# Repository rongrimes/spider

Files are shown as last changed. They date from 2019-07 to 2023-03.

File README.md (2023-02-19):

# Heavy Metal Hollywood Spider
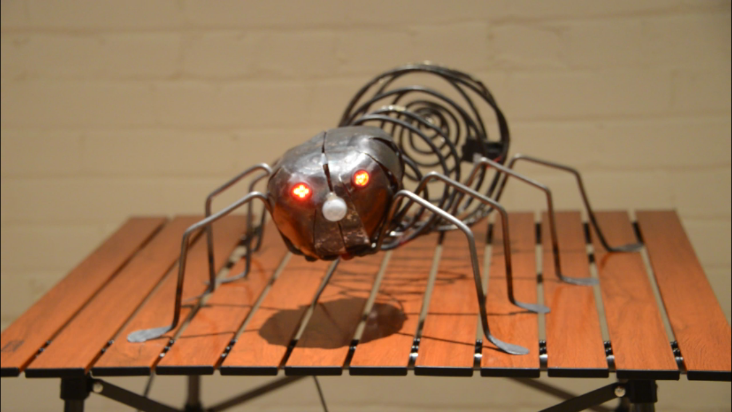
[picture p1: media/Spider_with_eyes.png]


**Heavy Metal Hollywood Spider** is an _*animatronics*_ project and is the fusion of two interests:
* Art Metal class
* Raspberry Pi and related hardware software.

As with the Chocolate Box News Reader ("paxnews"), the project grew organically. That is I had a rough idea how it would all look at the end but progress was consistent over a number of months. You could say that, he is an organic spider (best kind!).

Ultimately, HMHS became a successful Halloween prop.

## Components:
* [Raspberry Pi Zero W](https://www.buyapi.ca/product/raspberry-pi-zero-w/)
* Eyes: 2 clusters of 4 RGB LEDs
* [Adafruit I2S 3W Stereo Speaker Bonnet for Raspberry Pi](https://www.buyapi.ca/product/adafruit-i2s-3w-stereo-speaker-bonnet-for-raspberry-pi-mini-kit/)
  * includes 2 speakers 
* [PIR sensor](https://www.buyapi.ca/product/hc-sr501-pyroelectric-infrared-pir-motion-sensor-detector-module/)
* [LED string (white) or similar](https://www.staples.com/5ft-15-Soft-White-String-Lights-with-Timer-74445/product_2724775)
* [Simple RF M4 Receiver - 315MHz Momentary Type](https://www.buyapi.ca/product/simple-rf-m4-receiver-315mhz-momentary-type/)
* [Keyfob 4-Button RF Remote Control - 315MHz](https://www.buyapi.ca/product/keyfob-4-button-rf-remote-control-315mhz/)

## Spider Construction
The spider grew "organically" over two semesters of the **Art Metal** class held at <a href="https://www.danforthcti.com/">Danforth Collegiate</a> in the body shop workshop, under the auspices of the <a href="https://www.tdsb.on.ca/Adult-Learners/Learn4Life">TDSB Adult Learner Program</a> (Toronto District School Board). [Thanks to Phil and Toby for their guidance.]

## General Operations
The spider sensor resides in the nose and detects motion from pets/humanoids/zombie  up to 5 metres away (<a href="https://www.adafruit.com/product/189" target="_blank">possibly works on zombies, not guaranteed</a>).

On pet/humanoid/zombie detection:
* Spider is dozing: The cyan eyes and body lights twitch every few seconds. Until someone/thing comes by.
* Spider goes on alert: The cyan eyes and body lights start flashing rapidly.
* Spider gets angry: The red eyes then transition up to full brightness.
* Spider emits warning noises: A short sound clip plays twice (or other count) or until the pet/humanoid/zombie goes out of range.
* All clear, Spider goes back to sleep: The red eyes then transition down.
* Spider goes back to dozing.

### Spider video
Spider video.

(Click and view the raw file in a separate window.).

### Spider Control Subsystem
A 4-Button 315Mhz Keyfob RF Remote Control controls parameters of the spider: Sound On/Off, Sound Volume, Eye Intensity.

The keyfob controls a Simple RF M4 Receiver> with results fed through to four GPIO pins via separate simple voltage splitters to translate 5V to 3.3V (2.8V actually).

The program *key_parms.py* watches the remote control and updates a shared json file used by _spider.py_.

### Schematic
See schematic.  
(Remote control content is not shown.)

## Operations
Start spider with _crontab_:
```
@reboot rm -f /home/pi/python/spider/ospid.txt # JOB_ID_1; Remove pid file to prevent mulitiple incursions of spider.
@reboot sleep 1 && ~pi/run_spider.sh           # JOB_ID_2; start spider.
@reboot sleep 2 && stdbuf -oL ~pi/python/spider/key_parms.py >> /tmp/spider.txt  # JOB_ID_3; start key controller.
```

## Fob Commands
The key Fob/RF receiver controls parameters for operation: A Voice prompt guides the operator for the steps.
 ready for power off.  
1: Press D to get attention.  
2. Press D for the menu.  
   A > Sound On/Off  
   B > Sound Volume  
   C > Maximum eye intensity  
   D > Play the menu (and a seong press will Return to the outer shell ("1")).  
3. Three consecutive presses of D cause spider to shutdown and be ready for power off.  

## Voice Prompt
For the prommt voice clips, I used the text-to-voice service from [IBM Watson](https://text-to-speech-demo.ng.bluemix.net/). Most of the voices are slowed a little from their original speeds to add gravitas. A json file holds the key of voice clips to files, but also holds the markeed up text sent to Watson  in case the text needs editing.

## FAQ
Q: Why _Hollywood_?  
A: Well, we... the spider and me... live on Hollywood Cres.

***
Ron Grimes  
Toronto  
Started:     January 2019  
Last Update: November 2020

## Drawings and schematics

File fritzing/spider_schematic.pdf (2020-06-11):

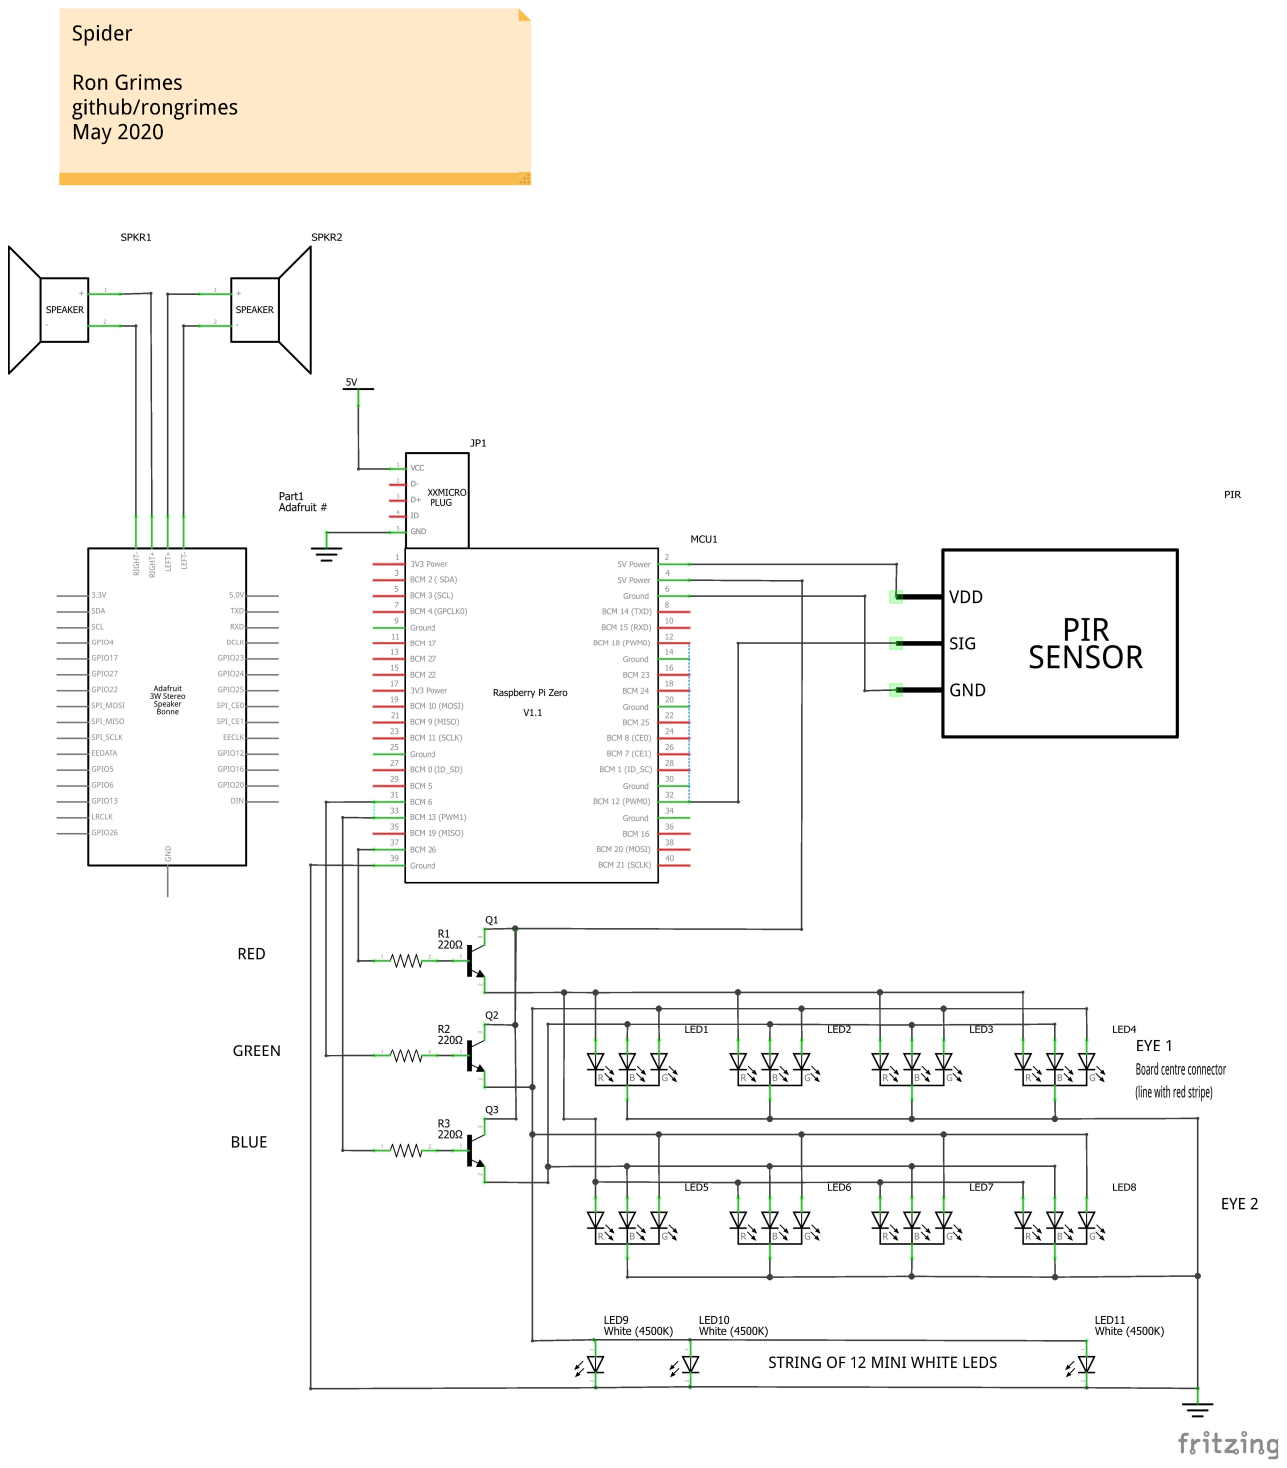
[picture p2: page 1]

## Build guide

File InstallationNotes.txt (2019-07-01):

Installation Notes for the Spider/Pi Zero
=========================================
(Notes: You will need to add reboots at opportune places).

1. Load Raspbian Stretch (not Lite); Img file 3.4GB

2. Load in to Pi Zero.

3. Standard initial settings, plus:
   In Raspberry Pi Config:
   a. Set platform name: raspberrypiZ1   
   b. set password.
   c. Enable ssh
   In Add/Remove Software:
   a. GNOME Onscreen Keyboard
   
4. Install:
   a. sudo apt install vim
   
5. Increase Swapsize:
    a. Stop the swap. sudo dphys-swapfile swapoff.
    b. Modify the size of the swap. As root , edit the file /etc/dphys-swapfile and modify the variable CONF_SWAPSIZE : CONF_SWAPSIZE=1024. ...
    c. Start the swap. sudo dphys-swapfile swapon.
	(ref: https://raspberrypi.stackexchange.com/questions/41150/virtual-keyboard-activation)

6. Install on-screen virtual keyboard.
    sudo apt-get install matchbox-keyboard
	(https://raspberrypi.stackexchange.com/questions/41150/virtual-keyboard-activation)
	
7. Create ~pi/python/spider

7. Load spider files from backup.

8. Load Speaker bonnet driver:
   curl -sS https://raw.githubusercontent.com/adafruit/Raspberry-Pi-Installer-Scripts/master/i2samp.sh | bash
   (ref: https://learn.adafruit.com/adafruit-speaker-bonnet-for-raspberry-pi/raspberry-pi-usage)

9. sudo apt install gnome-schedule
   This installs a GUI crontab entry system.
   Maybe unnecessary, but manual crontab was not producing results.

10. Alternative: "crontab -e" with:
    @reboot rm /home/pi/python/spider/ospid.txt # JOB_ID_2
    @reboot sleep 2 && ~pi/run_spider.sh # JOB_ID_1

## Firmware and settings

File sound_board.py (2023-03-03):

#!/usr/bin/python3
import asyncio
import json
import os
from random import randint

#----------------------------------------------------------------------------------------
class Sound_board:
    sound_dir       = "/home/pi/python/spider/clips/"
    sound_parmfile  = sound_dir + "soundparms.json"
    voice_volume    = 40000      # range: 0 - max  (1000000?)
    max_volume      = 40000    # range: 0 - max
    max_volume_limit = 60000 # can scale up the volume but limit it to this.

    def __init__(self):
        try:
            with open(self.sound_parmfile, "r") as f:
                self.sound_clips = json.load(f)
        except FileNotFoundError:
            print(self.sound_parmfile + ": not found. Reloading.")
            self._load_clips()
#       print(self.sound_clips)
        self.last_clip = None if len(self.sound_clips) == 0 else randint(0, len(self.sound_clips)-1)
#       self.clips_init = True     # lets us spin up through the clips if we use an async iterator

#---------------------------------------------------------------------------------
    def print_clips(self, sound_clips):
        for i, f in enumerate(sound_clips):
            print(f"{i}\t{f}")
        print()
        
    def _load_clips(self):
        self.sound_clips = []
        if not os.path.isdir(self.sound_dir):
            print(self.sound_dir + ": Sound dir does not exist.")
            return            # dir doesn't exist,
                              #    return empty list = no sound files
        for file in os.listdir(self.sound_dir):
            _, file_extension = os.path.splitext(file)     # discard filename part
            if file_extension[1:] in {"mp3"}:    # set of allowed sound files
                entry = [self.sound_dir + file, 1.0]   # it would be nicer as a tuple, but we can't store
                                                  #     it in a json file.
                self.sound_clips.append(entry)

#---------------------------------------------------------------------------------
    def _get_sound_index(self):
        self.last_clip += 1
        if self.last_clip >= len(self.sound_clips):
            self.last_clip = 0
        return self.last_clip

#---------------------------------------------------------------------------------
    async def _play_sound2(self, sound_file, volume):
        t_sound = await asyncio.create_subprocess_exec("mpg123", "-q",
                "-f " + str(volume),
                sound_file, stdout=asyncio.subprocess.PIPE)
        await t_sound.wait()   # wait for the mpg123 process to finish

    async def play_sound(self, my_globals, indx=None):
        if self.last_clip is None: # no sound files
            return

        limit = 2     # Play no more than 2x.

        sound_entry = self.sound_clips[self._get_sound_index()] if indx is None else self.sound_clips[indx]

        sound_file = sound_entry[0]
        scale      = sound_entry[1]
        volume = int(my_globals.spider_parms["VOLUME"] * scale)       # scale up volume as needed.
        volume = min(volume, self.max_volume_limit)

#       print(f"{sound_file}, {volume}")
        if not os.path.isfile(sound_file):
            return                              # file does not exist.

        for i in range(limit):
            if my_globals.spider_parms["END_REQUEST"]:
                break   # OK, we're gone!
            await self._play_sound2(sound_file, volume)

            if i == limit - 1:
                return   # don't wait after the last iteration completed
            await asyncio.sleep(1)

if __name__ == "__main__":
    s = Sound_board()

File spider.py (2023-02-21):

#!/usr/bin/python3
##!env python3

# Installation Notes:
# ------------------
#
# The speakers are: Adafruit Speaker Bonnet for Raspberry Pi, see:
#    https://learn.adafruit.com/adafruit-speaker-bonnet-for-raspberry-pi
#
# Driver load instructions are at:
#    https://learn.adafruit.com/adafruit-speaker-bonnet-for-raspberry-pi/raspberry-pi-usage
#
# Sound player: mpg123
#    sudo apt install mpg123

import asyncio
import datetime
import os
import RPi.GPIO as GPIO
import signal
from sys import exit

# Local imports
from globals import My_globals
from sound_board import Sound_board

# Set RPi ports
pir_pin = 12

led_RED = 13
led_GRN = 6
led_BLU = 26

wait_change = 0.1    # time to wait for pir to change before looking again.

ospid_file = "/home/pi/python/spider/ospid.txt"

#---------------------------------------------------------------
#   functions that do things - non async
def eyes_setup(pin_no):
    GPIO.setup(pin_no, GPIO.OUT)     # activate output
    pwm_eyes = GPIO.PWM(pin_no, 100)  # duty cycle: 100Hz; max value allowed.
    pwm_eyes.start(0)
    return pwm_eyes

def make_eye_intensities(max_int):
    global eyes_intensity
    eyes_steps = 40
    eyes_intensity = {int(((10**(r/eyes_steps)-1)*max_int/9)+0.99) for r in range(0,eyes_steps+1)}
                       # exponential series {0..max_intensity} - created as a set to remove duplicates
    eyes_intensity = sorted(list(eyes_intensity))     # convert set to list to ensure sequencing.
                                                      # sort: since the set returns in undetermined order.
    print(eyes_intensity)
    return eyes_intensity 

# Arm signal to end program.
def handler(signum, frame):
    ''' A sigint interrupt will get caught here, and will in effect be the same as
        getting a ^C at the keyboard.'''
    print("\nterm signal received")
    raise KeyboardInterrupt

#---------------------------------------------------------------
#   async functions
async def eyes_change(pin_no, UP=True):
    eye_change_transition = 5 # seconds
    delay =  eye_change_transition / len(eyes_intensity)   # seconds
    direction = 1 if UP else -1

    for eyes_level in eyes_intensity[::direction]:
        pin_no.ChangeDutyCycle(eyes_level)
        await asyncio.sleep(delay)

async def flash_GB():
    ''' Flash Green/Blue LEDs in the eyes, and the white string of LEDs.'''
    slow_flash = 5       # seconds between flashes during quiet period
    fast_flash = 0.5     # seconds between flashes when animation_active is True

    print("flash_GB  co-routine")

    seconds = slow_flash          # Force flash on first entry
    while my_globals.spider_parms["END_REQUEST"] == False:
        if my_globals.animation_active or seconds >= slow_flash: # Flash every (slow_flash) seconds
            GPIO.output(led_GRN, GPIO.HIGH)
            GPIO.output(led_BLU, GPIO.HIGH)
            await asyncio.sleep(0.1)
            GPIO.output(led_GRN, GPIO.LOW)
            GPIO.output(led_BLU, GPIO.LOW)
            seconds = 0
        else:
            seconds += fast_flash
        await asyncio.sleep(fast_flash)

    print("flash_GB shutting down")

#---------------------------------------------------------------
async def track_myglobals():
    print("track_myglobals co-routine")
    
    # reload my_globals every 0.5 seconds
    while True:
        my_globals.get_spider_parms()   # since they can change by key_parms
        if my_globals.spider_parms["END_REQUEST"]:
            break
        await asyncio.sleep(0.5)
    print("track_myglobals shutting down")

#---------------------------------------------------------------
async def track_pir():
    def tick_str(ticks):
        ticks = f"{ticks}"
        return ticks + len(ticks) * "\b"          # add equiv # of backspaces to back space over the number.

    wait_on = 7        # wait this long (seconds) to see it's a real mamalian critter or zombie (not guaranteed)
    max_ticks = int(wait_on * 1 / wait_change)  # ticks in (wait_on) seconds.

    print("track_pir co-routine")
    
    # wait until PIR drops during initialization - may/may not be high
    while GPIO.input(pir_pin):
        await asyncio.sleep(wait_change)

    # Generate max _eye_intensity list here just once.
    max_eye_intensity = my_globals.spider_parms["MAX_INT"]  # get MAX-INT so we can check for future changes

    while True:     # main loop - only exited with a "return" statement.
        while my_globals.spider_parms["END_REQUEST"] == False:
            # Wait for pir line to go high
            if GPIO.input(pir_pin) == False:
                await asyncio.sleep(wait_change)     # still quiet
                continue

#           The PIR line is now high: check for a false positive
            print("/ \b", end="", flush=True)

            # Check spider parms
            if my_globals.spider_parms["MAX_INT"] != max_eye_intensity:
                max_eye_intensity = my_globals.spider_parms["MAX_INT"]
                eyes_intensity = make_eye_intensities(max_eye_intensity) 

            my_globals.animation_active = True    # Enable sound and start quick flashing

            to_ticks = 0                       # timeout_ticks
            while to_ticks < max_ticks:        # now let's wait to see if it drops within wait_on seconds.
                if my_globals.spider_parms["END_REQUEST"]:
                    print("track_pir shutting down")
                    return

                await asyncio.sleep(wait_change)
                if GPIO.input(pir_pin):
                    to_ticks +=1  # pir line still high, increment ticks.
                else:     # line falls within short period... it's a false positive
                    break              # print report and and return to while True loop.

            else:        # line is high, and we have exceeded max_ticks - there is a critter out there.
                break    # out of while True loop
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

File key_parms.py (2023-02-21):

#!/usr/bin/python3
##!env python3

import json
import os
import RPi.GPIO as GPIO
import sys
import signal
import subprocess
from time import sleep

# Set RPi ports
key_A = 22
key_B = 27
key_C = 17
key_D = 4
 
spider_parmfile = "/home/pi/python/spider/spiderparms.json"
speech_loc      = "/home/pi/python/spider/speech/"
voices_file     = speech_loc + "speech_legend.json"

voice_volume = 40000      # range: 0 - max  (1000000?)
max_volume   = 1000000    # range: 0 - max  (1000000?)

max_eye_intensity = 80    # max is 100, but may draw too much power.
min_eye_intensity = 40

#default values
spider_parms = {"SOUND_ON": False, "VOLUME":10000, "MAX_INT":25,
                "END_REQUEST": False} # 0 <= VOLUME  <= 100000+

#---------------------------------------------------------------
def get_spider_parms():
    global spider_parms
    try:
        with open(spider_parmfile, "r") as f:
            spider_parms = json.load(f)
    except FileNotFoundError:
        print(spider_parmfile + ": not found. Using defaults.")
        # use defaults defined above
        pass

#---------------------------------------------------------------
def put_spider_parms():
    global spider_parms
    with open(spider_parmfile, "w") as f:
        json.dump(spider_parms, f)

#---------------------------------------------------------------------------------
# load voices structure
def get_voices_file():
    global voices
    try:
        with open(voices_file, "r") as f:
            voices = json.load(f)
    except FileNotFoundError:
        print(voices_file + ": not found. key_parms.py is now terminating.")
        sys.exit()

#---------------------------------------------------------------------------------
# set sound: T/F
def set_sound():
    global spider_parms

    changed = False
    speak("08-Press-A-Sound")
    speak("11-Press-D-Exit")

    while True:
        if spider_parms["SOUND_ON"]:
            speak("09-Sound-On")
        else:
            speak("10-Sound-Off")

        while True:
            letter = get_letter()
            if letter == "A":
                spider_parms["SOUND_ON"] = not spider_parms["SOUND_ON"] 
                changed = True
                break

            if letter == "D":
                return changed

#---------------------------------------------------------------------------------
def volume_increase(volume):
    if volume == 0:
        return 1000
    volume += max(int(volume * 0.25), 10000)
    return round(min(volume, max_volume), -3)

def volume_decrease(volume):
    volume -= max(int(volume * 0.25), 10000)
    return round(max(0, volume), -3)

def set_volume():
    global spider_parms

    changed = False

    if spider_parms["VOLUME"] == 0:
        speak("10-Sound-Off")
    elif spider_parms["VOLUME"] == max_volume:
        speak("15-Sound-Max")

#   Read menu
    speak("18-Press-AC-IncrDecr")
    speak("19-Press-B-Play")
    speak("11-Press-D-Exit")

    while True:
        letter = get_letter()
        if letter == "A":
            spider_parms["VOLUME"] = volume_increase(spider_parms["VOLUME"])
            if spider_parms["VOLUME"] == max_volume:
                speak("15-Sound-Max")
            else:
                speak("16-Volume-Up", volume=spider_parms["VOLUME"])
            changed = True
            continue

        if letter == "C":
            spider_parms["VOLUME"] = volume_decrease(spider_parms["VOLUME"])
            if spider_parms["VOLUME"] == 0:
                speak("10-Sound-Off")
            else:
                speak("17-Volume-Down", volume=spider_parms["VOLUME"])
            changed = True
            continue

        if letter == "B":
            speak("01-Hello-Spider", volume=spider_parms["VOLUME"])
            continue

        if letter == "D":
            return changed


#---------------------------------------------------------------------------------
# set eye intensity values.
def eye_increase(intensity):
    intensity += 10
    return min(intensity, max_eye_intensity)

def eye_decrease(intensity):
    intensity -= 10
    return max(min_eye_intensity, intensity)

def set_eyepower():
    global spider_parms

    changed = False
#   Read menu
    speak("25-Press-AC-IncrDecr-Eye")
    speak("11-Press-D-Exit")

    while True:
        letter = get_letter()
        if letter == "A":
            spider_parms["MAX_INT"] = eye_increase(spider_parms["MAX_INT"])
            if spider_parms["MAX_INT"] >= max_eye_intensity:
                speak("21-Eye-Max")
            else:
                speak("23-Eye-Up")
            changed = True
            continue

        if letter == "C":
            spider_parms["MAX_INT"] = eye_decrease(spider_parms["MAX_INT"])
            if spider_parms["MAX_INT"] <= min_eye_intensity:
                speak("22-Eye-Min")
            else:
                speak("24-Eye-Down")
            changed = True
            continue

        if letter == "D":
            return changed

#---------------------------------------------------------------------------------
# get input
def get_letter():
    while True:
        for key, letter in [(key_A, "A"), (key_B, "B"), (key_C, "C"), (key_D, "D")]:
            if GPIO.input(key):  # check key
                return letter
        sleep(0.1)      # 100ms

#---------------------------------------------------------------------------------
# Wait for D key
def wait_for_D():
    only_D = True
    while get_letter() != "D":
        only_D = False
    return only_D

#---------------------------------------------------------------------------------
def speak(voice_key, volume=voice_volume):
    if voice_key not in voices["files"]:
        print("speak: voice_key not found:" , voice_key)
        return

    sound_file = speech_loc + voices["files"][voice_key]["filename"]
    mpg123 = "exec sudo -u pi mpg123 -q -f " + str(volume) + " " + sound_file

    popen = subprocess.Popen(mpg123, stdout=subprocess.PIPE, shell=True,
        preexec_fn=os.setsid)
    popen.wait()

#---------------------------------------------------------------------------------
def shutdown_spider():
    speak("07-Goodbye")

    spider_parms["END_REQUEST"] = True
    put_spider_parms()
    sleep(3)         # sleep to endure spider comes down.
    # and rest to false for next startup
    spider_parms["END_REQUEST"] = False
    put_spider_parms()

    command = "/usr/bin/sudo /sbin/shutdown now"
    popen = subprocess.Popen(command.split(), stdout=subprocess.PIPE)
    output = popen.communicate()[0]
    print(output)
    popen.wait()
    sleep(100)

#---------------------------------------------------------------------------------
# Arm signal to end program.
def sig_handler(signum, frame):
    ''' A sigint interrupt will get caught here, and will in effect be the same as
        getting a ^C at the keyboard.'''
    raise KeyboardInterrupt
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

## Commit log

2019-04-30 cosmetic: ospidfile type fixed.
    [spider.py]
2019-07-01 pwmtest: sets eye brightness & suitable for calibrating how bright we want the eyes. (Answer: max 25-50) s_parms: New value for MAX_INT for eye brightness. spiderparms: json file with configuration.-
2019-07-01 spider.py: LED intensities converted from int to allowed to float; PWM allows float values.
2019-07-18 Textual: replaced "led" with "eyes" for eyes-related functions in prep for moving eyes code to own thread.
    [spider.py]
2019-07-18 Fixed bug introduced by putting sounds into its own directory.
    [spider.py]
2019-07-20 sound-board extracted from main source file and placed in own file.
2020-04-29 Commit of simplification of sound module by ending the thread for each run. kill_spider: to manually remove the ospid file. (Update: check if it's prsent first).
2020-05-09 Restore green light code relocated to appear after threads have terminated.
2020-05-11 spider fritzing image and pdf loaded
    [Spider.fzz]
2020-05-11 Updated with schematic pdf
2020-05-16 log keeping removed.
    [Spider.fzz]
2020-05-17 Outer block loop with KeyboardError/SigInt timer reduced to 0.1s to make more responsive.
2020-05-25 Wiring corrected and power redrawn to be more realistic and accurate.
    [Spider.fzz]
2020-05-29 pi GPIO.wait_edge coding replaced by simpler GPIO.input coding. Enables correct handling of new input while in shutdown from previous animation cycle.
    [spider.py]
2020-06-11 Error corrected in diagram - removed extraneous ground symbol.
    [Spider.fzz]
2020-10-11 Wait time in mainloop increased a bit.
    From 0.1s to 0.25 - not consequential.
    Also corrected a spelling error in a comment.
    [spider.py]
2020-10-11 README.md updated with notes on the keyfob controlleri.
    The controller consists of:
    * Keyfob 4-Button RF Remote Control - 315MHz
    * Simple RF M4 Receiver - 315MHz Momentary Type
    * Program: key_parms.py
2020-10-12 Write of PID moved to later position
    If Greenlight killed the initialization (because we weren't running with sudo)
    then the ospid.txt file was stopping future runs of the programs and the ospid.txt
    file needed to be removed manually (or via reboot).
    [spider.py]
2023-02-02 pwmtest.py removed - not useful
2023-02-04 keyparms updated to ignore unpredictable RuntimeError for rising channel error.
    [key_parms.py]
2023-02-18 several changes: iclu removing GPIO KEYRISING code - didn't work when started from a system boot and via crontab.
    [key_parms.py]
2023-02-20 Cleaned up randint usage, added __main__ code for future devp, cleaned print of clips.
2023-02-21 a sleep(5) was added to enable the sound card to properly initialize after a reboot.
    [key_parms.py]
2023-02-24 bug fix: end_request now handles corretly
    [sound_board.py]
2023-03-03 Added avoidance if sound file not present
    [sound_board.py]
